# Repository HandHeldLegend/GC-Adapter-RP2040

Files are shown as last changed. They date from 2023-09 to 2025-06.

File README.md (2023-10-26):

# GC Pocket Adapter+ Firmware
This is the official Github page for the GC Pocket Adapter+ from Hand Held Legend.

## Software and PCB License
<br />This firmware and PCB model are licensed under a <a rel="license" href="http://creativecommons.org/licenses/by-nc-sa/3.0/">Creative Commons Attribution-NonCommercial-ShareAlike 3.0 Unported License</a>.

## 3D Models License

<br />The 3D shell and buttons are licensed under a <a rel="license" href="http://creativecommons.org/licenses/by/4.0/">Creative Commons Attribution 4.0 International License</a>.

## Shop Link
- [GC Pocket Adapter+ Kit (Includes 3D Printed Parts)](https://handheldlegend.com/products/4-port-gc-pocket-adapter-gamecube-to-usb-c-controller-adapter-diy-kit)

## Detailed Information
All of our guides
are listed on [our Wiki linked here](https://wiki.handheldlegend.com).

## 3D Parts
All 3D parts are in the [/3d directory](https://github.com/HandHeldLegend/GC-Adapter-RP2040/tree/master/Production/3D) on this Github repo in STEP format. A 3D STEP file is provided for accurate reference on the PCB dimensions.

## Features
- 4 USB Input modes.
- 4 controller ports with rumble supported.
- Adapts GameCube controllers for use on Windows, Mac, Android, and Nintendo Switch.
- Nintendo Switch only supports 8ms polling rate (Locked by Nintendo Switch).
- RGB status lights for all 4 controllers.
- Two buttons to change input mode.

## Basic Operation
- When the device is plugged in, the LED light shows a color to indicate which mode it is in. 
	- Yellow - Nintendo Switch Pro Controller
	- Purple - GameCube OEM Mode 
	- Green - XInput (Xbox 360 Controllers)
    - Pink - Slippi (1khz polling)

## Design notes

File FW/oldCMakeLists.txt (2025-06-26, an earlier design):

cmake_minimum_required(VERSION 3.13)

# Set the C standard
set(CMAKE_C_STANDARD 11)
set(CMAKE_CXX_STANDARD 17)

include($ENV{PICO_SDK_PATH}/pico_sdk_init.cmake)

project(gc_adapter_rp2040 C CXX ASM)

pico_sdk_init()

include_directories(
  include
	common/include
  common/include/devices
  common/include/generated
  common/include/switch
  common/include/usb
  common/include/utilities
  common/include/ll
)

add_executable(${PROJECT_NAME}
  src/main.c 
  src/joybus_itf.c 
  src/rgb_itf.c 

  common/utilities/rgb.c 
  common/utilities/joybus.c 
  common/utilities/interval.c

  common/ll/adapter_ll_rp2040.c 

  common/usb/desc_bos.c 
  
  common/adapter.c
  common/adapter_tusb.c 

  common/adapter_defines.c 
  common/adapter_settings.c 

  common/usb/xinput_driver.c 
  common/usb/ginput_driver.c

  common/switch/switch_analog.c 
  common/switch/switch_commands.c 
  common/switch/switch_spi.c 

  common/devices/gcinput.c 
  common/devices/swpro.c 
  common/devices/webusb.c 
  common/devices/xinput.c
)

file(MAKE_DIRECTORY ${CMAKE_CURRENT_LIST_DIR}/include/generated)
pico_generate_pio_header(${PROJECT_NAME} ${CMAKE_CURRENT_LIST_DIR}/pio/ws2812.pio OUTPUT_DIR ${CMAKE_CURRENT_LIST_DIR}/include/generated)
pico_generate_pio_header(${PROJECT_NAME} ${CMAKE_CURRENT_LIST_DIR}/pio/joybus.pio OUTPUT_DIR ${CMAKE_CURRENT_LIST_DIR}/include/generated)

target_compile_definitions(${PROJECT_NAME}
	PRIVATE
	PICO_XOSC_STARTUP_DELAY_MULTIPLIER=64
	PICO_DEFAULT_UART_TX_PIN=12
	PICO_DEFAULT_UART_RX_PIN=13
  ADAPTER_MCU_TYPE=1
	#PICO_DEFAULT_BOOT_STAGE2=boot2_generic_03h
	#PICO_FLASH_SPI_CLKDIV=8
	)

# Pull in pico libraries that we need
target_link_libraries(${PROJECT_NAME}
  PRIVATE
  pico_stdlib
  pico_bootrom
  pico_multicore
  pico_platform
  pico_rand

  hardware_gpio
  hardware_adc
  hardware_flash
  hardware_pio
  hardware_dma
  hardware_pwm
  hardware_spi
  hardware_sync
  hardware_timer
  hardware_irq

  tinyusb_device
  tinyusb_board
)

pico_enable_stdio_usb(${PROJECT_NAME} 0)
pico_enable_stdio_uart(${PROJECT_NAME} 0)

pico_add_extra_outputs(${PROJECT_NAME})

add_custom_command(TARGET ${PROJECT_NAME}
 					POST_BUILD
					COMMAND ${CMAKE_COMMAND} 
					-DTARGET_NAME=${PROJECT_NAME}
					-DTARGET_PATH=${CMAKE_CURRENT_SOURCE_DIR}
					-P ${CMAKE_SOURCE_DIR}/manifest.cmake
					COMMENT "Updating version in manifest.json"
					WORKING_DIRECTORY ${CMAKE_SOURCE_DIR}
					)

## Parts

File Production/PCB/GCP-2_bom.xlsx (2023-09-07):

# | Reference | Qty | Value | Footprint | DNP | MPN
1 | C1 | 1 | 47uF 6.3v | Capacitor_Tantalum_SMD:CP_EIA-3216-18_Kemet-A
2 | C2 | 1 | 6.8uF | Capacitor_SMD:C_0603_1608Metric
3 | C3 | 1 | 2.2uF | Capacitor_SMD:C_0603_1608Metric
4 | C4, C5, C7, C8, C9 | 5 | 100n | Capacitor_SMD:C_0402_1005Metric
5 | C6 | 1 | 1u | Capacitor_SMD:C_0402_1005Metric
6 | C10 | 1 | 100n | Capacitor_SMD:C_0201_0603Metric
7 | D1 | 1 | CUS08F30 | Diode_SMD:D_SOD-323_HandSoldering
8 | F1 | 1 | Fuse | Fuse:Fuse_1206_3216Metric_Pad1.42x1.75mm_HandSolder
9 | J1 | 1 | USB4105-GF-A-060 | hhl:GCT_USB4105-GF-A-060 |  | USB4105-GF-A-060
10 | J2 | 1 | GC 1 | hhl:GameCubeHeader |  | DNP
11 | J3 | 1 | GC 2 | hhl:GameCubeHeader |  | DNP
12 | J4 | 1 | GC 3 | hhl:GameCubeHeader |  | DNP
13 | J5 | 1 | GC 4 | hhl:GameCubeHeader |  | DNP
14 | L1, L2, L3, L4 | 4 | SK6805-EC-15 | hhl:SK6805-EC-15 |  | SK6805-EC-15
15 | R1, R2 | 2 | 27 | Resistor_SMD:R_0201_0603Metric
16 | R3, R7, R10, R11, R12, R13 | 6 | 1k | Resistor_SMD:R_0201_0603Metric
17 | R4, R14 | 2 | 10k | Resistor_SMD:R_0201_0603Metric
18 | R5, R6 | 2 | 5.1k | Resistor_SMD:R_0201_0603Metric
19 | R8, R9 | 2 | 330 | Resistor_SMD:R_0201_0603Metric
20 | SW1, SW2, SW3 | 3 | 1TS026A-1000-0550 | hhl:1TS026A-1000-0550 |  | 1TS026A-1000-0550
21 | TP1, TP2, TP3, TP4, TP5 | 5 | TestPoint | TestPoint:TestPoint_Pad_1.0x1.0mm |  | DNP
22 | U1 | 1 | RP2040 | Package_DFN_QFN:QFN-56-1EP_7x7mm_P0.4mm_EP3.2x3.2mm |  | RP2040
23 | U2 | 1 | GD25Q80EEIGR | hhl:USON-8-EP(2x3) |  | GD25Q80EEIGR
24 | U3 | 1 | XC6222 | hhl:SOT-89-5 |  | XC6222B331PR-G
25 | Y1 | 1 | Crystal_GND3 | Crystal:Resonator_SMD_Murata_CSTxExxV-3Pin_3.0x1.1mm |  | CSTNE12M0GH5L000R0

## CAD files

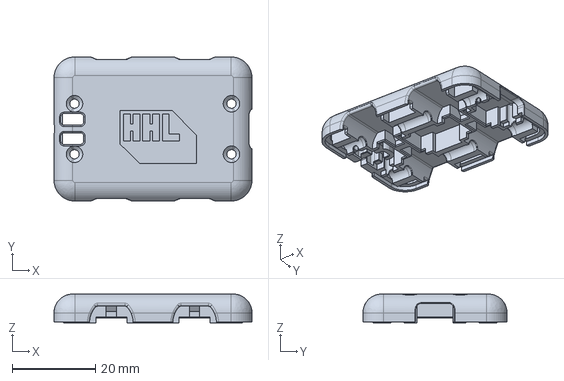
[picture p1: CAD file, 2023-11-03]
Production/3D/Fusion Exports/UpperShell.step
47.7 x 34.7 x 6.95 mm

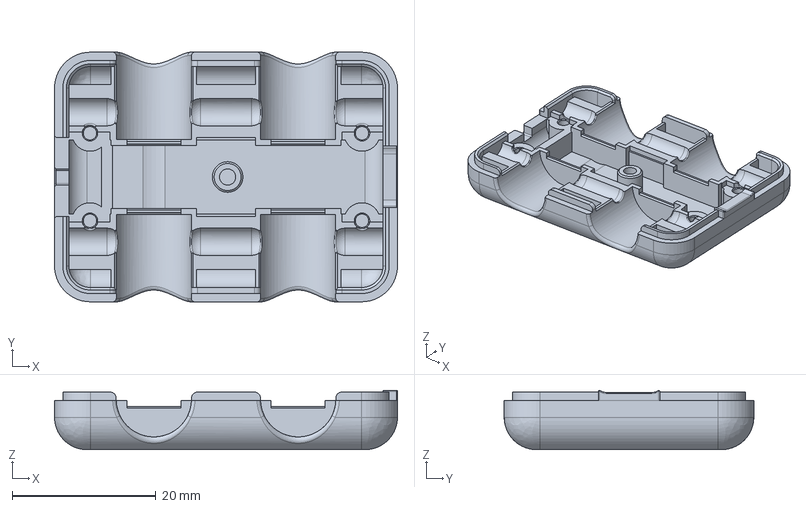
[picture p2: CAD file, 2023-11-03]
Production/3D/Fusion Exports/LowerShell.step
47.7 x 34.7 x 8.24 mm

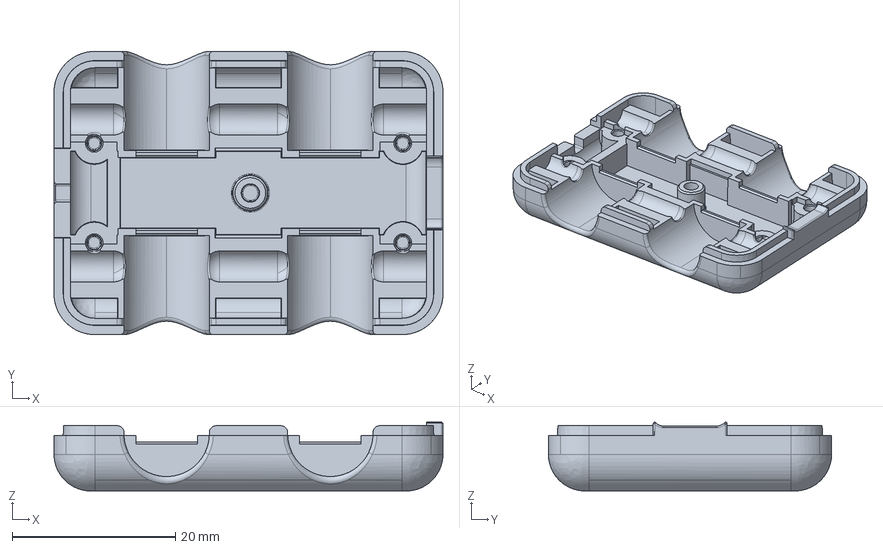
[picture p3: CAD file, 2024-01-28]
Production/3D/LowerShell.stp
47.7 x 34.7 x 8.45 mm

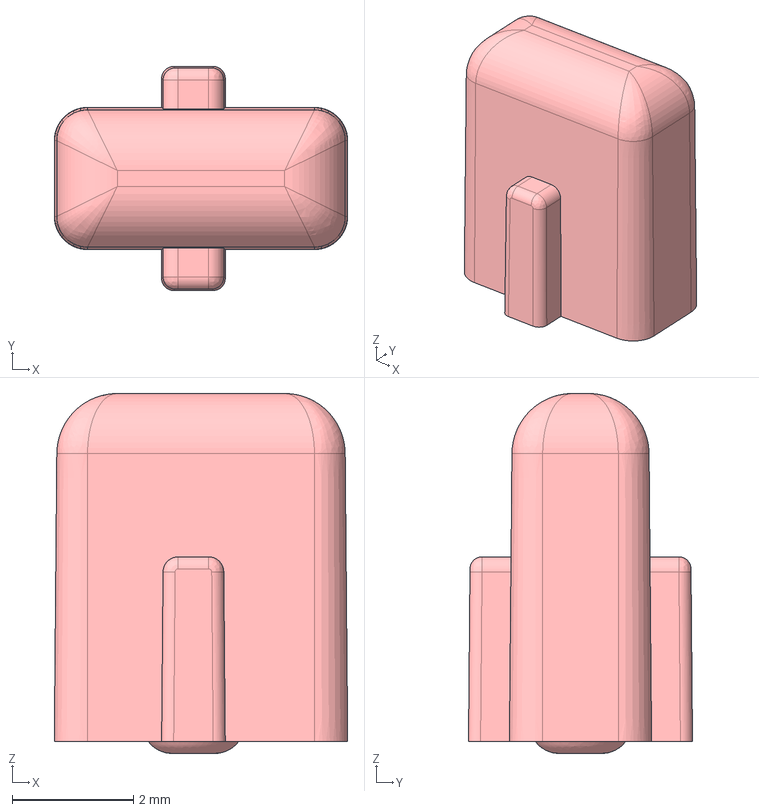
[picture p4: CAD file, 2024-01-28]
Production/3D/Button.step
4.85 x 3.70 x 5.95 mm

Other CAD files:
Production/3D/UpperShell.stp

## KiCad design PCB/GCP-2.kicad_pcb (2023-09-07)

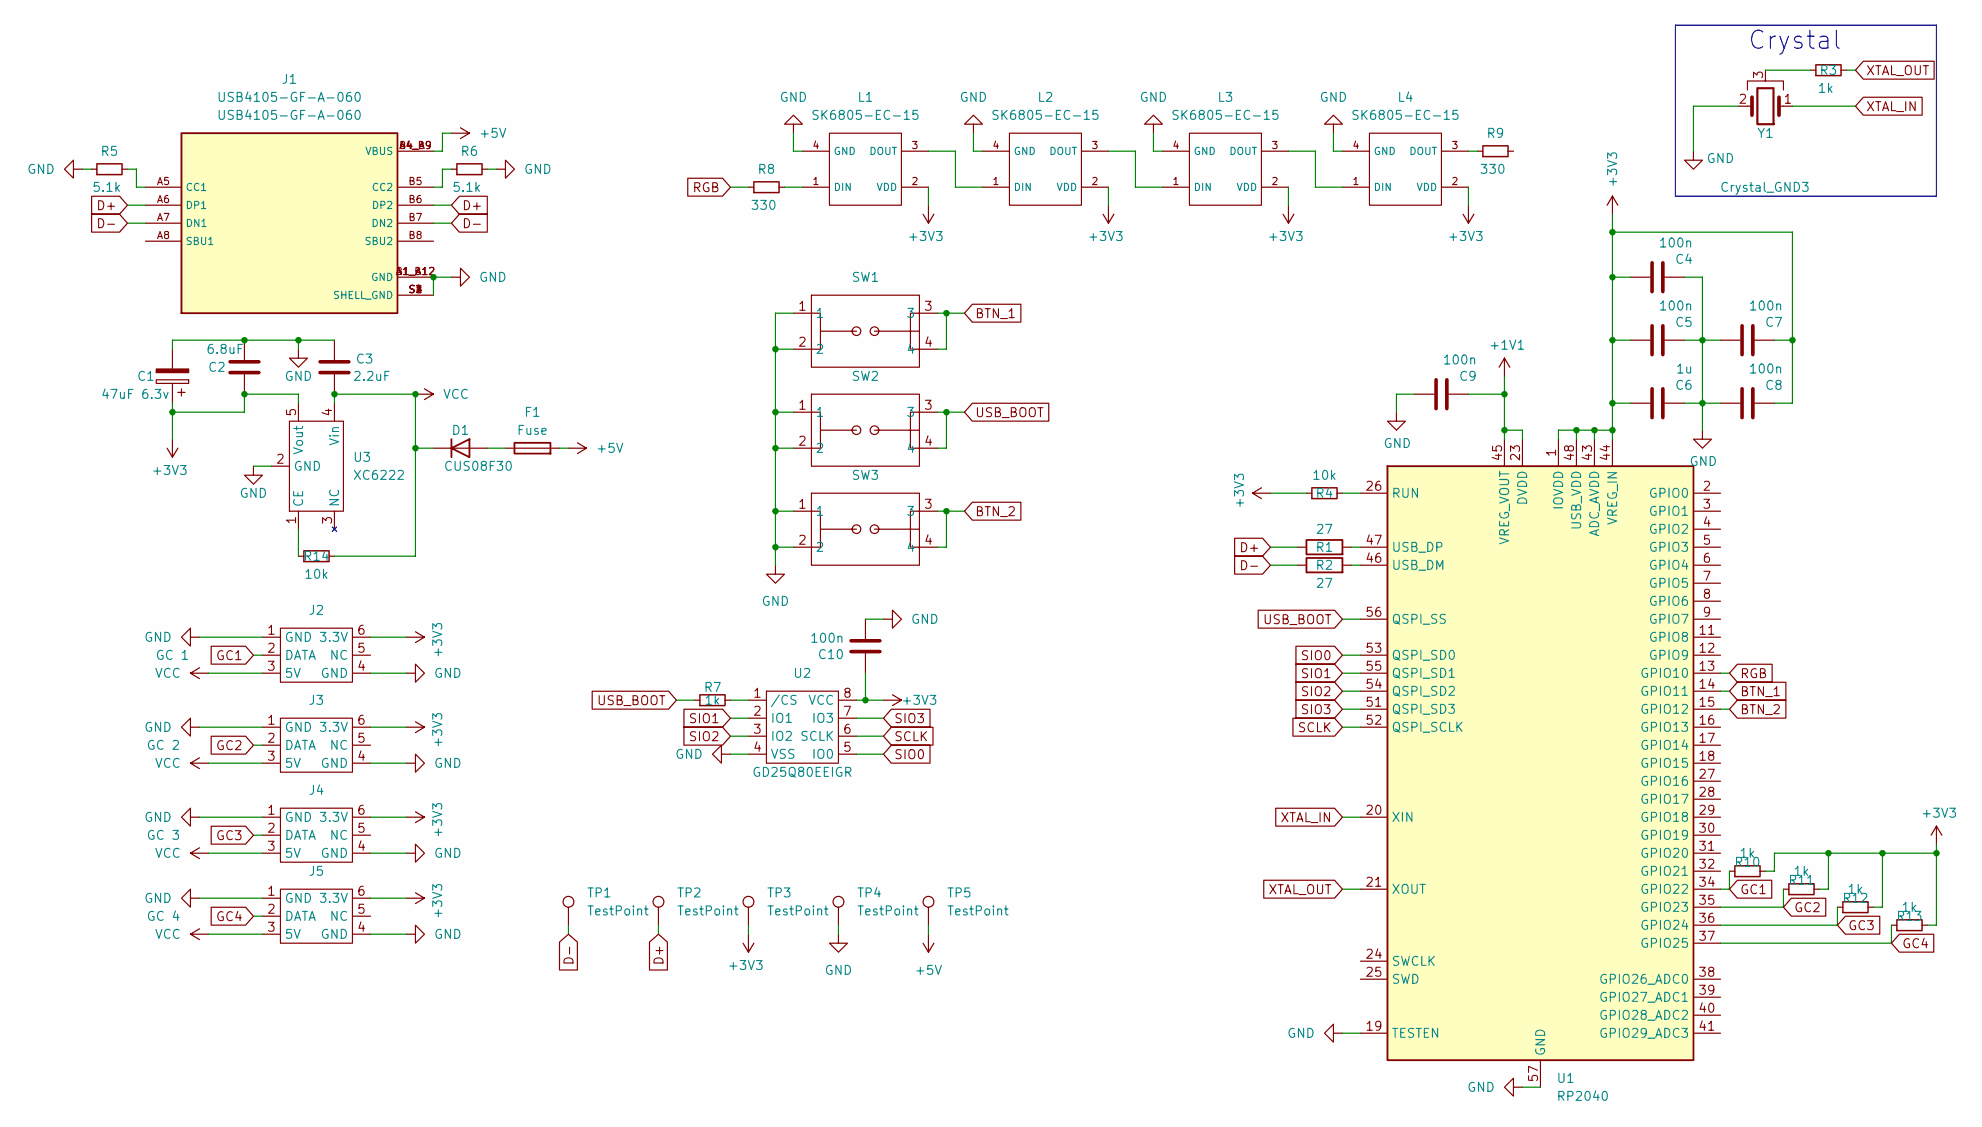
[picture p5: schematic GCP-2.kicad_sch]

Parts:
C1: 47uF 6.3v; CP_EIA-3216-18_Kemet-A
C2: 6.8uF; C_0603_1608Metric
C3: 2.2uF; C_0603_1608Metric
C4, C5, C7, C8, C9: 100n; C_0402_1005Metric
C6: 1u; C_0402_1005Metric
C10: 100n; C_0201_0603Metric
D1: CUS08F30; D_SOD-323_HandSoldering
F1: Fuse; Fuse_1206_3216Metric_Pad1.42x1.75mm_HandSolder; LCSC C69680
J1: USB4105-GF-A-060; GCT_USB4105-GF-A-060; MPN USB4105-GF-A-060
J2: GC 1; GameCubeHeader
J3: GC 2; GameCubeHeader
J4: GC 3; GameCubeHeader
J5: GC 4; GameCubeHeader
L1, L2, L3, L4: SK6805-EC-15
R1, R2: 27; R_0201_0603Metric
R3, R7, R10, R11, R12, R13: 1k; R_0201_0603Metric
R4, R14: 10k; R_0201_0603Metric
R5, R6: 5.1k; R_0201_0603Metric
R8, R9: 330; R_0201_0603Metric
SW1, SW2, SW3: 1TS026A-1000-0550; MPN 1TS026A-1000-0550; LCSC C913778
TP1, TP2, TP3, TP4, TP5: TestPoint; TestPoint_Pad_1.0x1.0mm
U1: RP2040; QFN-56-1EP_7x7mm_P0.4mm_EP3.2x3.2mm
U2: GD25Q80EEIGR; USON-8-EP(2x3); MPN GD25Q80EEIGR; LCSC C2874937
U3: XC6222; SOT-89-5; MPN XC6222B331PR-G
Y1: Crystal_GND3; Resonator_SMD_Murata_CSTxExxV-3Pin_3.0x1.1mm; MPN CSTNE12M0GH5L000R0

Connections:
+1V1: C9.2, U1.23 (DVDD), U1.45 (VREG_VOUT), U1.50 (DVDD)
+3V3: C1.1, C2.1, C4.1, C5.1, C6.1, C7.2, C8.2, C10.1, J2.6 (3.3V), J3.6 (3.3V), J4.6 (3.3V), J5.6 (3.3V), L1.2 (VDD), L2.2 (VDD), L3.2 (VDD), L4.2 (VDD), R4.1, R10.2, R11.2, R12.2, R13.2, TP3.1, U1.1 (IOVDD), U1.10 (IOVDD), U1.22 (IOVDD), U1.33 (IOVDD), U1.42 (IOVDD), U1.43 (ADC_AVDD), U1.44 (VREG_IN), U1.48 (USB_VDD), U1.49 (IOVDD), U2.8 (VCC), U3.5 (Vout)
+5V: F1.2, J1.A4_B9 (VBUS), J1.B4_A9 (VBUS), TP5.1
BTN_1: SW1.3, SW1.4, U1.14 (GPIO11)
BTN_2: SW3.3, SW3.4, U1.15 (GPIO12)
D+: J1.A6 (DP1), J1.B6 (DP2), R1.1, TP2.1
D-: J1.A7 (DN1), J1.B7 (DN2), R2.1, TP1.1
GC1: J2.2 (DATA), R10.1, U1.34 (GPIO22)
GC2: J3.2 (DATA), R11.1, U1.35 (GPIO23)
GC3: J4.2 (DATA), R12.1, U1.36 (GPIO24)
GC4: J5.2 (DATA), R13.1, U1.37 (GPIO25)
GND: C1.2, C2.2, C3.1, C4.2, C5.2, C6.2, C7.1, C8.1, C9.1, C10.2, J1.A1_B12 (GND), J1.B1_A12 (GND), J1.S1 (SHELL_GND), J1.S2 (SHELL_GND), J1.S3 (SHELL_GND), J1.S4 (SHELL_GND), J2.1 (GND), J2.4 (GND), J3.1 (GND), J3.4 (GND), J4.1 (GND), J4.4 (GND), J5.1 (GND), J5.4 (GND), L1.4 (GND), L2.4 (GND), L3.4 (GND), L4.4 (GND), R5.1, R6.2, SW1.1, SW1.2, SW2.1, SW2.2, SW3.1, SW3.2, TP4.1, U1.19 (TESTEN), U1.57 (GND), U2.4 (VSS), U3.2 (GND), Y1.2
unnamed: D1.2 (A), F1.1
unnamed: J1.A5 (CC1), R5.2
unnamed: J1.B5 (CC2), R6.1
unnamed: L1.1 (DIN), R8.2
unnamed: L1.3 (DOUT), L2.1 (DIN)
unnamed: L2.3 (DOUT), L3.1 (DIN)
unnamed: L3.3 (DOUT), L4.1 (DIN)
unnamed: L4.3 (DOUT), R9.1
unnamed: R3.1, Y1.3
unnamed: R4.2, U1.26 (RUN)
unnamed: R2.2, U1.46 (USB_DM)
unnamed: R1.2, U1.47 (USB_DP)
unnamed: R7.2, U2.1 (/CS)
unnamed: R14.1, U3.1 (CE)
RGB: R8.1, U1.13 (GPIO10)
SCLK: U1.52 (QSPI_SCLK), U2.6 (SCLK)
SIO0: U1.53 (QSPI_SD0), U2.5 (IO0)
SIO1: U1.55 (QSPI_SD1), U2.2 (IO1)
SIO2: U1.54 (QSPI_SD2), U2.3 (IO2)
SIO3: U1.51 (QSPI_SD3), U2.7 (IO3)
USB_BOOT: R7.1, SW2.3, SW2.4, U1.56 (QSPI_SS)
VCC: C3.2, D1.1 (K), J2.3 (5V), J3.3 (5V), J4.3 (5V), J5.3 (5V), R14.2, U3.4 (Vin)
XTAL_IN: U1.20 (XIN), Y1.1
XTAL_OUT: R3.2, U1.21 (XOUT)

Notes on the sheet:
Crystal

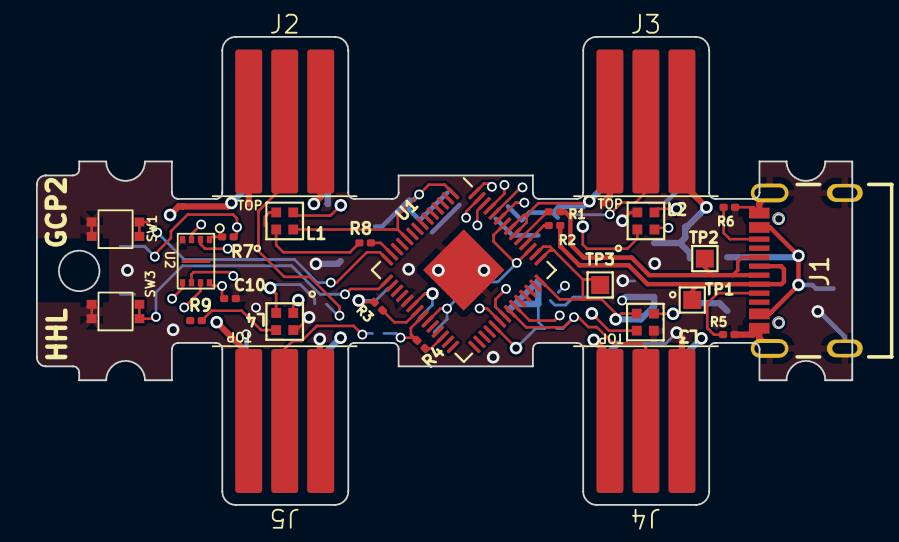
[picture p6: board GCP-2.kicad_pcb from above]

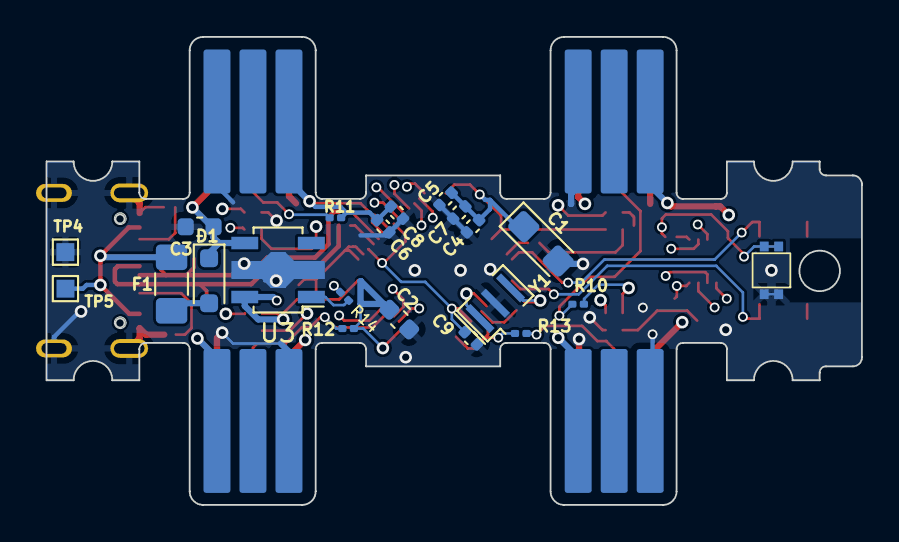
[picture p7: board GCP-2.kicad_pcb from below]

Board: 4 copper layers, 45.3 x 26.0 mm, 47 parts (21 on the bottom side), 36 nets.

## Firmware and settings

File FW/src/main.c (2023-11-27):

#include "main.h"

bool cb_adapter_hardware_test()
{
    adapter_ll_hardware_setup();
    rgb_init();

    // Check GPIO levels if they are all HIGH indicating pull-ups are working
    bool gpio_fail = false;
    if(!adapter_ll_gpio_read(JOYBUS_PORT_1))
    {
        gpio_fail=true;
    }

    if(!adapter_ll_gpio_read(JOYBUS_PORT_2))
    {
        gpio_fail=true;
    }

    if(!adapter_ll_gpio_read(JOYBUS_PORT_3))
    {
        gpio_fail=true;
    }

    if(!adapter_ll_gpio_read(JOYBUS_PORT_4))
    {
        gpio_fail=true;
    }

    // If the test has failed, we can return a fail
    if(gpio_fail) return false;

    // Flash all three rgb colors then we can return our test value
    rgb_set_instant(COLOR_RED.color);
    sleep_ms(1000);
    rgb_set_instant(COLOR_GREEN.color);
    sleep_ms(1000);
    rgb_set_instant(COLOR_BLUE.color);
    sleep_ms(1000);
    rgb_set_instant(COLOR_WHITE.color);
    sleep_ms(1000);
    rgb_set_instant(0x00);
    sleep_ms(1000);
    return true;
}

int main()
{
    adapter_main_init();
    adapter_main_loop();
}

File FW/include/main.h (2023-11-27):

#include "adapter_includes.h"
#include "ws2812.pio.h"
#include "joybus.pio.h"

#define RGB_PIO pio1
#define RGB_SM 0

#define UTIL_RGB_PIN   10
#define UTIL_RGB_COUNT 4
#define UTIL_RGBW_EN 0

#define JOYBUS_PIO pio0

#define JOYBUS_PORT_1 22
#define JOYBUS_PORT_2 23
#define JOYBUS_PORT_3 24
#define JOYBUS_PORT_4 25

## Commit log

2023-10-25 Update
    - 1000hz slippi
    - Switch rumble procon mode
    - fun
    [main.c, main.h]
2023-11-02 Fix XInput/Switch mode
2023-11-03 Update 3D
    [Button.iges, LowerShell.iges, LowerShell.step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]
2023-11-03 3d files
    Fix weird geometry on screw holes
    [LowerShell.iges, LowerShell.step]
2023-11-03 Fix non-planar geometry
    [Button.iges, LowerShell.iges, LowerShell.step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]
2024-01-28 Updated firmware build
    - Slippi/XInput more consistent 1khz input mode
    [Button.step, LowerShell.step, LowerShell.stp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]
2024-02-07 Fix switch mode scaling update
2024-05-21 Update frame alignment
2025-06-26 Update to use Pico SDK Extension
